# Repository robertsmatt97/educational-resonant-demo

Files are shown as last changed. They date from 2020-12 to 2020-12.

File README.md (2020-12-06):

# Educational Demos for Resonant Converter Phenomena

This repository stores all of the project files corresponding to the paper published under the same name. The files are necessary for building, simulating, and operating the converter described in the paper.

## Navigating the Project Files

1. User Manual
    - A detailed guide for setting up and operating the educational board.
    - The User Manual is listed already in the published paper but will be regularly updated here.
    
2. Bill of Materials
    - An Excel spreadsheet that contains every component used for the educational converter.
    - URLs, part numbers, and prices are listed.
    - Mouser cart link attached (To be added) is at the bottom of the spreadsheet for easy purchasing.
    - It is recommended to buy extra parts.
    
3. GERBER Files Zip File
    - A zip file for PCB manufacturers for convenient PCB purchasing.
    - The zip file is suitable for Smart Prototyping, which was used to create the prototype.
    - Some PCB manufacturers require different export options. The User Manual describes how to export it correctly.
    
4. "Videos" Folder
    - Videos demonstrating the capabilities of the converter. 
    - YouTube links are listed below as well. (To be added)
    - Demonstration 1: (To be added)
    - Demonstration 2: (To be added)
    
5. "KiCAD" Folder
    - KiCAD project files containing the schematic and PCB of the converter.
    - Library paths may need to be configured to see symbols and footprints correctly.
    
6. "MATLAB" Folder
    - MATLAB scripts to show hypothetical, simulation, and converter data over different combinations of resonant converter design parameters.
    - 'Resonant_Design.m' shows hypothetical and simulation data only. The board does not need to be connected.
    - 'Resonant_Design_Serial.m' shows hypothetical, simulation, and converter data. The board needs to be connected, and the CCS script needs to be running.
    - MATLAB 2019b or higher is required to run the 'Resonant_Design_Serial.m' script. 
    
7. "LTSpice" Folder
    - Simulation files for the resonant converter. 
    - Configure the parameters where it is listed.
    - Follow the User Manual for instructions on additional operation.
    
8. "CCS" Folder
    - Code Composer Studio (CCS) project files containing the code needed for operation. 
    - The latest version of CCS is recommended for the converter to work.

## To-Do List

1. Add Mouser Cart link of all the components. 
2. Add YouTube links of video demonstrations.
3. Add more visuals to User Manual.
3. Add additional microcontroller features to shorten downtime for demonstrations.

## Contact Information for Help

You can contact me at my email below for assistance in getting the board to work. Please be detailed in your issues.
Email: robertsmatt97@gmail.com

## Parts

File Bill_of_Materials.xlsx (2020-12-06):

 | Grocery List | Bill of Materials
 |  | Bought | Item Name | Component Label | Part Number | Value | QTY | Price | Total | Datasheet URL | Column1 | Column2
 |  |  | Microcontroller | NA | LAUNCHXL-F280049C | NA | 1 | $36.00 | $36.00 | https://www.ti.com/tool/LAUNCHXL-F280049C#1
 |  |  | 2x10 Socket | J1...J4 | 90151-2320 | NA | 4 | $5.13 | $20.52 | https://www.mouser.com/ProductDetail/Molex/90151-2320?qs=WjPO6T6WDws63RVDMfLJfw%3D%3D
 |  |  | Single Headers | J5+ | 87891-0106 | NA | 14 | $0.21 | $2.94 | https://www.mouser.com/ProductDetail/Molex/87891-0106?qs=kNSQ05%252BLZoC2%252Bs81B6ycXA%3D%3D
 |  |  | MOSFET | Q | CSD18513Q5A | NA | 2 | $1.11 | $2.22 | https://www.mouser.com/ProductDetail/Texas-Instruments/CSD18513Q5A?qs=34RfhUjJmKfal%252BAkBmQt6Q%3D%3D
 |  |  | SPST Rocker Switches | SW | H8800VAAAB | NA | 4 | $1.06 | $4.24 | https://www.digikey.com/en/products/detail/bulgin/H8800VAAAB/9598452?s=N4IgTCBcDaIBIA4EAZkDUCCWBCIC6AvkA
 |  |  | Half Bridge Diodes | D | SL43-M3/57T | NA | 4 | $0.80 | $3.20 | https://www.mouser.com/ProductDetail/Vishay-General-Semiconductor/SL43-M3-57T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
 |  |  | Transformer | T | 750342864 | 50 uH | 1 | $5.76 | $5.76 | https://www.mouser.com/ProductDetail/Wurth-Elektronik/750342864
 |  |  | Resonant Inductor | Lr | 744373965120 | 12 uH | 1 | $2.81 | $2.81 | https://www.mouser.com/ProductDetail/Wurth-Elektronik/744373965120?qs=BZBei1rCqCCwoGZYfs3IVg%3D%3D
 |  |  | Resonant Capacitor 1 | Cr1 | C0805C473F3GECAUTO | 47 nF | 1 | $1.71 | $1.71 | https://www.mouser.com/ProductDetail/KEMET/C0805C473F3GECAUTO?qs=MLItCLRbWsw%2FcVYxjlXEdg%3D%3D
 |  |  | Resonant Capacitor 2 | Cr2 | GRM31C5C2A823JA01L | 82 nF | 2 | $0.71 | $1.42 | https://www.mouser.com/ProductDetail/Murata-Electronics/GRM31C5C2A823JA01L
 |  |  | Magnetizing Inductor | Lmag | 744373965120 | 12 uH | 3 | $2.81 | $8.43 | https://www.mouser.com/ProductDetail/Wurth-Elektronik/744373965120?qs=BZBei1rCqCCwoGZYfs3IVg%3D%3D
 |  |  | Half Bridge Capacitor | Crect | CM105X5R106M25AT | 10 uF | 2 | $0.30 | $0.60 | https://www.mouser.com/ProductDetail/Kyocera-Electronic-Components/CM105X5R106M25AT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
 |  |  | Input Capacitor | Cin | CM105X5R106M25AT | 10 uF | 2 | $0.30 | $0.60 | https://www.mouser.com/ProductDetail/Kyocera-Electronic-Components/CM105X5R106M25AT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
 |  |  | Input Loop Capacitor | Cinx | LLL31MR71C105MA01L | 1 uF | 1 | $0.48 | $0.48 | https://www.mouser.com/ProductDetail/Murata-Electronics/LLL31MR71C105MA01L
 |  |  | Output Capacitor | Cout | CM105X5R106M25AT | 10 uF | 2 | $0.30 | $0.60 | https://www.mouser.com/ProductDetail/Kyocera-Electronic-Components/CM105X5R106M25AT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
 |  |  | Divider Resistor 1 | Rdiv1 | AC0603FR-07100KL | 100 k | 1 | $0.10 | $0.10 | https://www.mouser.com/ProductDetail/Yageo/AC0603FR-07100KL?qs=UoPT7wUmgYKBKZ83mTH%252BSA%3D%3D
 |  |  | Divider Resistor 2 | Rdiv2 | AC0603FR-0720KL | 20 k | 1 | $0.10 | $0.10 | https://www.mouser.com/ProductDetail/Yageo/AC0603FR-0720KL?qs=UoPT7wUmgYLT1v%252BfpbzmVQ%3D%3D
 |  |  | Divider Resistor 3 | Rdiv3 | AC0603FR-07150KL | 150 k | 2 | $0.10 | $0.20 | https://www.mouser.com/ProductDetail/Yageo/AC0603FR-07150KL?qs=yhV1fb9g%2FKbGHv1fnPiGNw%3D%3D
 |  |  | Sensing Resistors | Rsns | WU732B15TTD25L0F | 25 m | 1 | $0.38 | $0.38 | https://www.mouser.com/ProductDetail/KOA-Speer/WU732B15TTD25L0F?qs=wUXugUrL1qyp9SvPCjqdBg%3D%3D
 |  |  | Boost IC | IC | TPS61085TDGKR | NA | 1 | $2.03 | $2.03 | https://www.mouser.com/ProductDetail/Texas-Instruments/TPS61085TDGKR
 |  |  | BB Diode | Dbb | PMEG2010AEH,115 | NA | 1 | $0.32 | $0.32 | https://www.mouser.com/ProductDetail/Nexperia/PMEG2010AEH115?qs=LOCUfHb8d9u7lcjEnyhX1g%3D%3D
 |  |  | BB Cap input | Cbb1 | CM105X5R106M25AT | 10 uF | 1 | $0.30 | $0.30 | https://www.mouser.com/ProductDetail/Kyocera-Electronic-Components/CM105X5R106M25AT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
 |  |  | BB Cap output | Cbb2 | CM105X5R106M25AT | 10 uF | 1 | $0.30 | $0.30 | https://www.mouser.com/ProductDetail/Kyocera-Electronic-Components/CM105X5R106M25AT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
 |  |  | BB Inductor | Lbb | CB2016T6R8M | 6.8 uH | 1 | $0.23 | $0.23 | https://www.mouser.com/ProductDetail/Taiyo-Yuden/CB2016T6R8M?qs=I6KAKw0tg2zlZTrvjf8dKA%3D%3D
 |  |  | BB FB Resistor 1 | Rfb1 | CR0805-FX-1133ELF | 113 k | 1 | $0.10 | $0.10 | https://www.mouser.com/ProductDetail/Bourns/CR0805-FX-1133ELF
 |  |  | BB FB Resistor 2 | Rfb2 | CRCW080518K0FKEA | 18 k | 1 | $0.10 | $0.10 | https://www.mouser.com/ProductDetail/Vishay-Dale/CRCW080518K0FKEA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
 |  |  | BB Comp R | Rcomp | ERA-3AED243V | 24 k | 1 | $0.25 | $0.25 | https://www.mouser.com/ProductDetail/Panasonic/ERA-3AED243V?qs=SWVmE3OSrOmwxrbbukvP0g%3D%3D
 |  |  | BB Comp C | Ccomp | ECH-U1C332GX5 | 3.3 nF | 1 | $0.37 | $0.37 | https://www.mouser.com/ProductDetail/Panasonic/ECH-U1C332GX5?qs=O9nxk9bDVAjmIw2e8gOaeQ%3D%3D
 |  |  | BB SS Cap | Cbb4 | CC0603KRX7R9BB104 | 100 nF | 1 | $0.10 | $0.10 | https://www.mouser.com/ProductDetail/Yageo/CC0603KRX7R9BB104?qs=sGAEpiMZZMvsSlwiRhF8qgFnKIgZe697WZ9nrpNTeGg%3D
 |  |  | BB IN Cap | Cbb3 | TMK107B7105KA-T | 1 uF | 1 | $0.11 | $0.11 | https://www.mouser.com/ProductDetail/Taiyo-Yuden/TMK107B7105KA-T
 |  |  | Gate Driver | G | LM5109BSD/NOPB | NA | 1 | $1.31 | $1.31 | https://www.mouser.com/ProductDetail/Texas-Instruments/LM5109BSD-NOPB?qs=QbsRYf82W3Gksst44udN8Q%3D%3D
 |  |  | GD Diode | Dboot | MBR1H100SFT3G | NA | 1 | $0.44 | $0.44 | https://www.mouser.com/ProductDetail/ON-Semiconductor/MBR1H100SFT3G
 |  |  | GD Bootstrap Resistor | Rboot | ESR03EZPF3R00 | 3 | 1 | $0.13 | $0.13 | https://www.mouser.com/ProductDetail/ROHM-Semiconductor/ESR03EZPF3R00
 |  |  | GD HS Cap | Cboot | CC0603KRX7R9BB104 | 100 nF | 1 | $0.10 | $0.10 | https://www.mouser.com/ProductDetail/Yageo/CC0603KRX7R9BB104?qs=sGAEpiMZZMvsSlwiRhF8qgFnKIgZe697WZ9nrpNTeGg%3D
 |  |  | GD Input Cap | Cgd | TMK107B7105KA-T | 1 uF | 1 | $0.11 | $0.11 | https://www.mouser.com/ProductDetail/Taiyo-Yuden/TMK107B7105KA-T
 |  |  | Signal Op Amp (2 in 1) | U1A…U1C | TLV2314IDR | NA | 1 | $0.94 | $0.94 | https://www.mouser.com/ProductDetail/Texas-Instruments/TLV2314IDR?qs=f4l5qYp%2Fy%252B7ipEpw1sGVYg%3D%3D
 |  |  | Filter Resistor 1 | Rfilt1 | AC0603FR-076K65L | 6.65 k | 2 | $0.10 | $0.20 | https://www.mouser.com/ProductDetail/Yageo/AC0603FR-076K65L?qs=ygRr%2FtkhtevehdG909PYfg%3D%3D
 |  |  | Filter Resistor 1 | Rfilt2 | AC0603FR-07665RL | 665 | 2 | $0.10 | $0.20 | https://www.mouser.com/ProductDetail/Yageo/AC0603FR-07665RL
`` |  |  | Filter Capacitor 1 | Cfilt2 | TMK107B7105KA-T | 1 uF | 2 | $0.11 | $0.22 | https://www.mouser.com/ProductDetail/Taiyo-Yuden/TMK107B7105KA-T
 |  |  | Filter Capacitor 2 | Cfilt1 | CC0603KRX7R9BB104 | 100 nF | 3 | $0.10 | $0.30 | https://www.mouser.com/ProductDetail/Yageo/CC0603KRX7R9BB104?qs=sGAEpiMZZMvsSlwiRhF8qgFnKIgZe697WZ9nrpNTeGg%3D
 |  |  | Frequency Resistors | Rfs | RC0603FR-0747KL | 47 k | 2 | $0.10 | $0.20 | https://www.mouser.com/ProductDetail/Yageo/RC0603FR-0747KL
 |  |  | Frequency Capacitor | Cfs | C0603C103J5RACTU | 10 n | 1 | $0.10 | $0.10 | https://www.mouser.com/ProductDetail/KEMET/C0603C103J5RACTU?qs=sGAEpiMZZMvsSlwiRhF8quIsB1QHp5lf6wge94WzHBg%3D
 |  |  | Potentiometer | RV | PTV09A-4020U-B103 | 1 k (min) | 1 | $0.80 | $0.80 | https://www.mouser.com/ProductDetail/Bourns/PTV09A-4020U-B102
 |  |  |  |  |  |  |  | Total Budget | $101.57

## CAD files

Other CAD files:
CCS/Resonant_Demo/Debug/optimizerAssistant/opt_for_speed__1/Main_Resonant.obj
CCS/Resonant_Demo/Debug/optimizerAssistant/opt_for_speed__2/Main_Resonant.obj
CCS/Resonant_Demo/Debug/optimizerAssistant/opt_for_speed__4/Main_Resonant.obj
CCS/Resonant_Demo/Debug/optimizerAssistant/opt_for_speed__0/Main_Resonant.obj
CCS/Resonant_Demo/Debug/optimizerAssistant/opt_for_speed__5/Main_Resonant.obj
CCS/Resonant_Demo/Debug/optimizerAssistant/opt_for_speed__3/Main_Resonant.obj
CCS/Resonant_Demo/Debug/device/device.obj
CCS/Resonant_Demo/Debug/driverlib/lin.obj
CCS/Resonant_Demo/Debug/optimizerAssistant/opt_for_speed__0/device/device.obj
CCS/Resonant_Demo/Debug/optimizerAssistant/opt_for_speed__0/PWM_Operation.obj
CCS/Resonant_Demo/Debug/optimizerAssistant/opt_for_speed__1/device/device.obj
CCS/Resonant_Demo/Debug/optimizerAssistant/opt_for_speed__2/device/device.obj
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

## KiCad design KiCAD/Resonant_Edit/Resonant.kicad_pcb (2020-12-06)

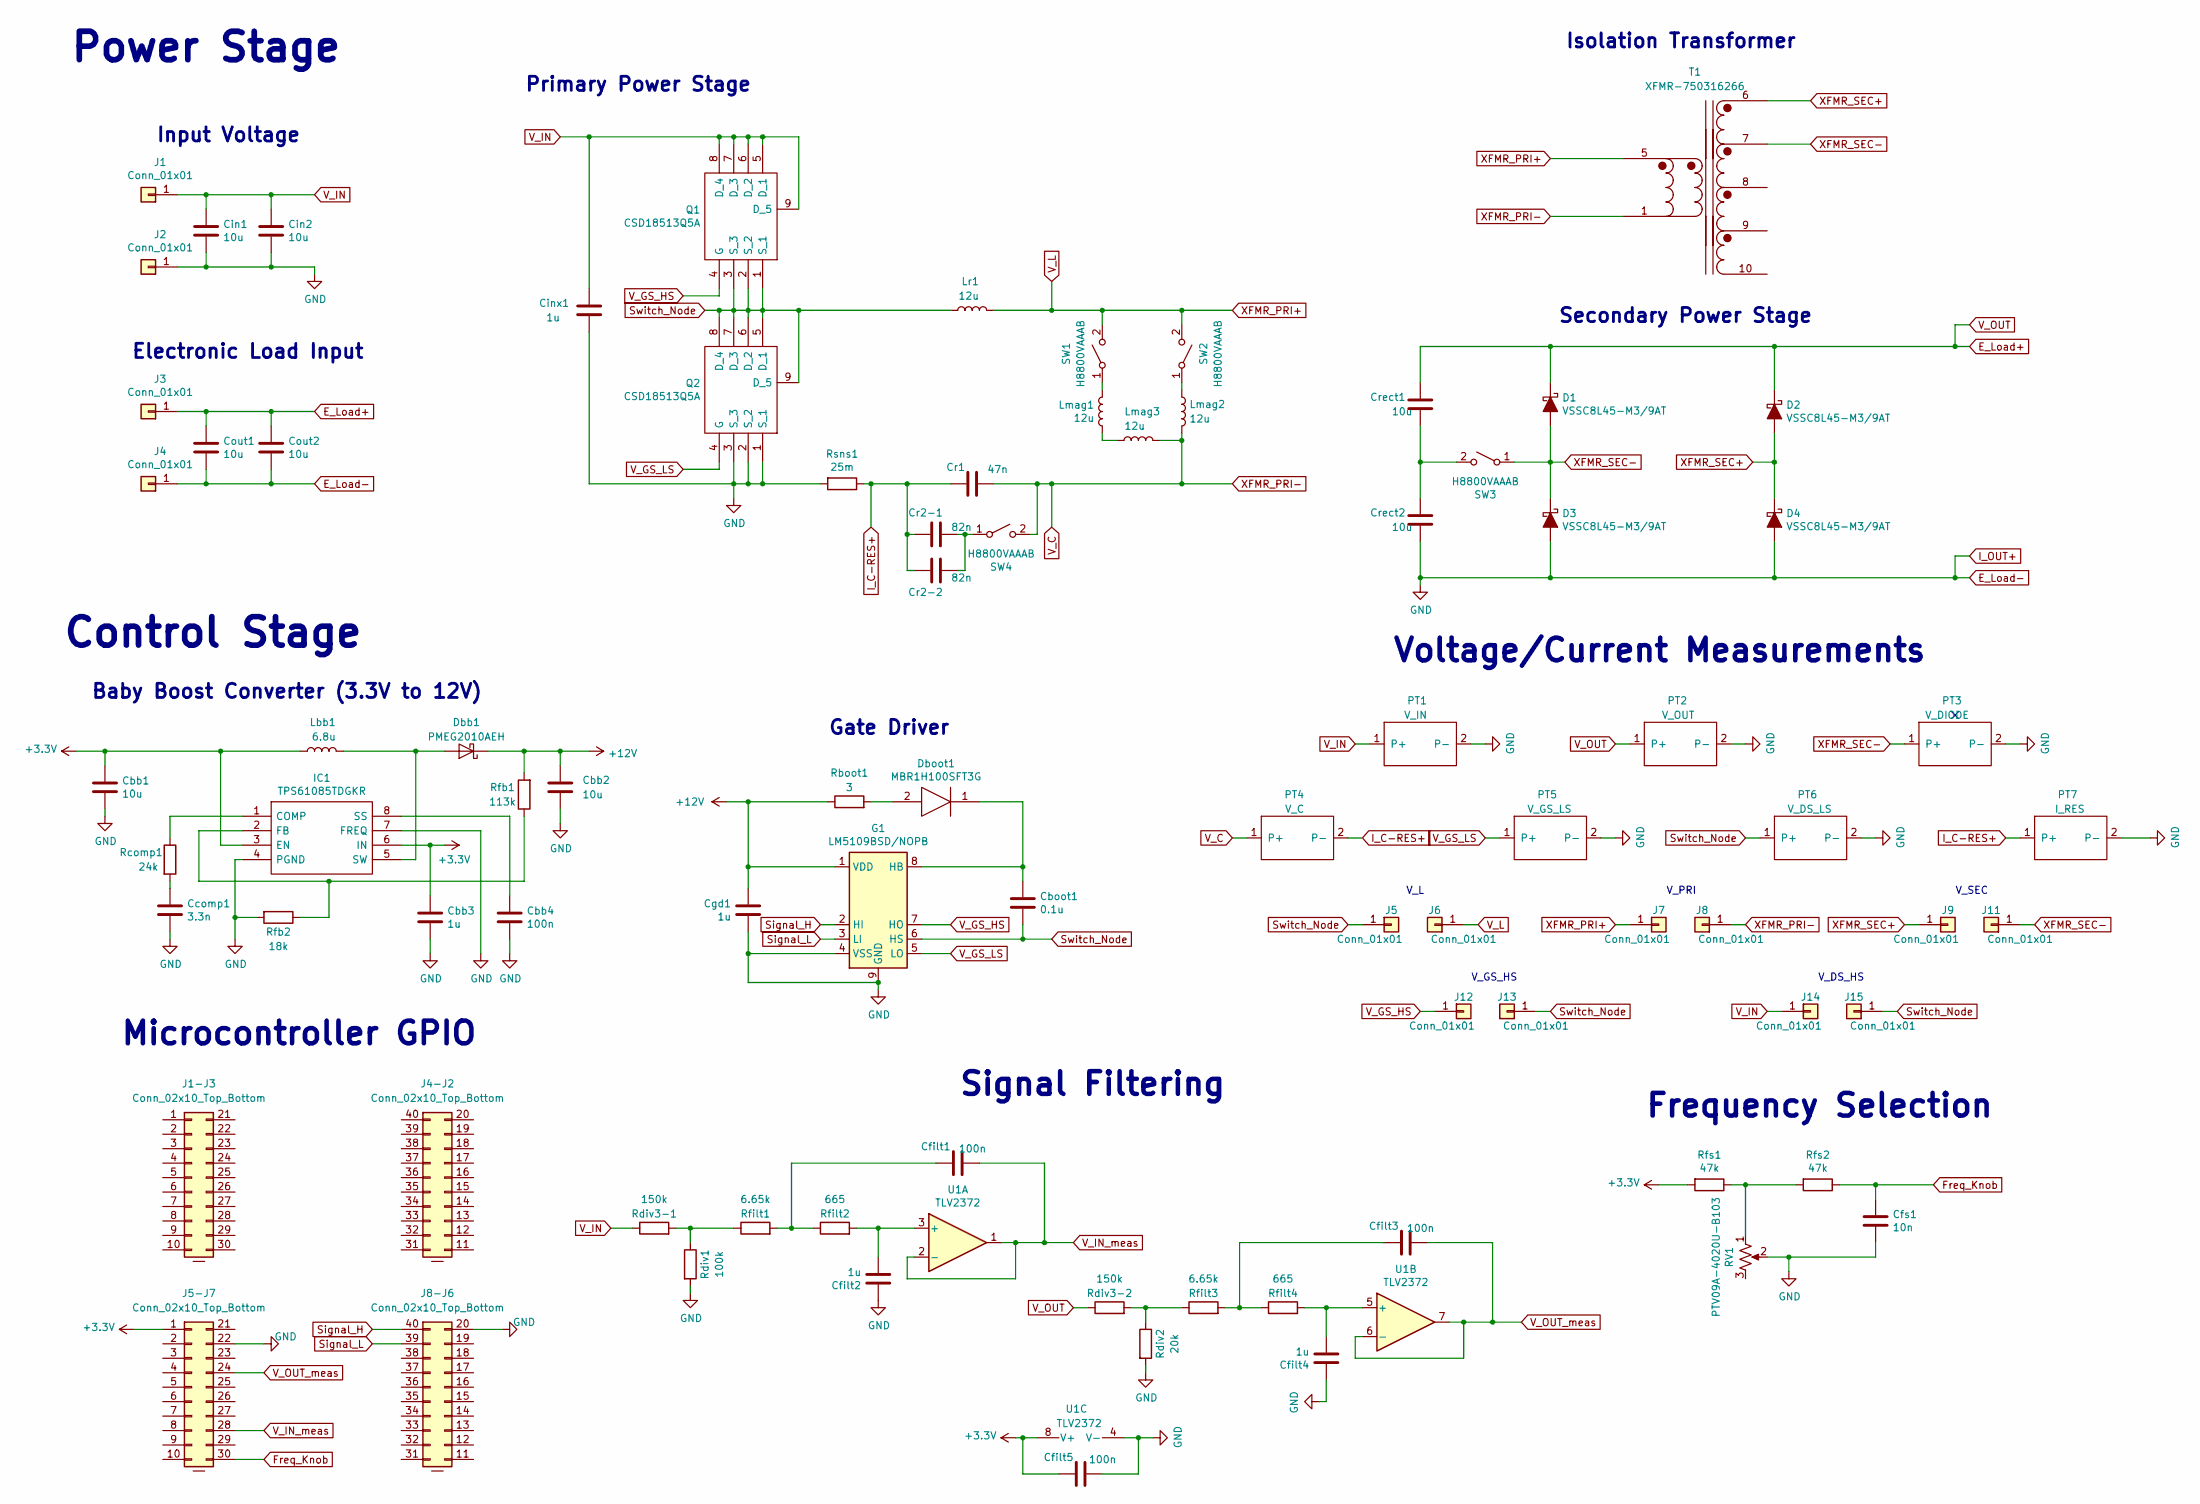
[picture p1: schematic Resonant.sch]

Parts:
Cbb1, Cbb2: 10u; C_0603_1608Metric
Cbb3: 1u; C_0603_1608Metric
Cbb4: 100n; C_0603_1608Metric
Cboot1: 0.1u; C_0603_1608Metric
Ccomp1: 3.3n; C_0805_2012Metric
Cfilt1, Cfilt3, Cfilt5: 100n; C_0603_1608Metric
Cfilt2, Cfilt4: 1u; C_0603_1608Metric
Cfs1: 10n; C_0603_1608Metric
Cgd1: 1u; C_0603_1608Metric
Cin1, Cin2: 10u; C_0603_1608Metric
Cinx1: 1u; LLL31MR71C105MA01L
Cout1, Cout2: 10u; C_0603_1608Metric
Cr1: 47n; C_0805_2012Metric
Cr2-1, Cr2-2: 82n; C_1206_3216Metric
Crect1, Crect2: 10u; C_0603_1608Metric
D1, D2, D3, D4: VSSC8L45-M3/9AT; VSSC8L45-M3_9AT
Dbb1: PMEG2010AEH; D_SOD-123
Dboot1: MBR1H100SFT3G; Mouser Part Number 863-MBR1H100SFT3G
G1: LM5109BSD/NOPB; LM5109BSD_NOPB
IC1: TPS61085TDGKR; Mouser Part Number 595-TPS61085TDGKR
J1, J2, J3, J4, J5, J6, J7, J8, J9, J11, J12, J13, J14, J15: Conn_01x01; PinHeader_1x01_P2.54mm_Vertical
J1-J3, J5-J7: Conn_02x10_Top_Bottom; 90151-2320_J1
J4-J2, J8-J6: Conn_02x10_Top_Bottom; 90151-2320_J2
Lbb1: 6.8u; L_0805_2012Metric
Lmag1, Lmag2, Lmag3: 12u; 744373965120
Lr1: 12u; 744373965120
PT1: V_IN; Probe_Test
PT2: V_OUT; Probe_Test
PT3: V_DIODE; Probe_Test
PT4: V_C; Probe_Test
PT5: V_GS_LS; Probe_Test
PT6: V_DS_LS; Probe_Test
PT7: I_RES; Probe_Test
Q1, Q2: CSD18513Q5A; Mouser Part Number 595-CSD18513Q5A
RV1: PTV09A-4020U-B103
Rboot1: 3; R_0603_1608Metric
Rcomp1: 24k; R_0603_1608Metric
Rdiv1: 100k; R_0603_1608Metric
Rdiv2: 20k; R_0603_1608Metric
Rdiv3-1, Rdiv3-2: 150k; R_0603_1608Metric
Rfb1: 113k; R_0805_2012Metric
Rfb2: 18k; R_0805_2012Metric
Rfilt1, Rfilt3: 6.65k; R_0603_1608Metric
Rfilt2, Rfilt4: 665; R_0603_1608Metric
Rfs1, Rfs2: 47k; R_0603_1608Metric
Rsns1: 25m; R_0612_1632Metric
SW1, SW2, SW3, SW4: H8800VAAAB
T1: XFMR-750316266; 750342864
U1: TLV2372; TLV2632

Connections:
+3V3: Cbb1.1, Cbb3.1, Cfilt5.1, IC1.3 (EN), IC1.6 (IN), J5-J7.1, Lbb1.1, Rfs1.2, U1.8 (V+)
+12V: Cbb2.2, Cgd1.1, Dbb1.1 (K), G1.1 (VDD), Rboot1.1, Rfb1.2
E_Load+: Cout1.1, Cout2.1, Crect1.1, D1.1 (K), D2.1 (K), J3.1, PT2.1 (P+), Rdiv3-2.1
E_Load-: Cbb1.2, Cbb2.1, Cbb3.2, Cbb4.2, Ccomp1.2, Cfilt2.1, Cfilt4.1, Cfilt5.2, Cfs1.2, Cgd1.2, Cin1.2, Cin2.2, Cinx1.2, Cout1.2, Cout2.2, Crect2.2, D3.2 (A), D4.2 (A), G1.4 (VSS), G1.9 (GND), IC1.4 (PGND), IC1.7 (FREQ), J2.1, J4.1, J5-J7.22 (Pin_12), J8-J6.20 (Pin_11), PT1.2 (P-), PT2.2 (P-), PT3.2 (P-), PT5.2 (P-), PT6.2 (P-), PT7.2 (P-), Q2.1 (S_1), Q2.2 (S_2), Q2.3 (S_3), RV1.2, Rdiv1.2, Rdiv2.2, Rfb2.2, Rsns1.2, U1.4 (V-)
Freq_Knob: Cfs1.1, J5-J7.30 (Pin_20), Rfs2.1
I_C-RES+: Cr1.1, Cr2-1.1, Cr2-2.1, PT4.2 (P-), PT7.1 (P+), Rsns1.1
unnamed: Cbb4.1, IC1.8 (SS)
unnamed: Cboot1.1, Dboot1.1, G1.8 (HB)
unnamed: Ccomp1.1, Rcomp1.2
unnamed: Cfilt1.1, Rfilt1.2, Rfilt2.1
unnamed: Cfilt2.2, Rfilt2.2, U1.3 (+)
unnamed: Cfilt3.1, Rfilt3.2, Rfilt4.1
unnamed: Cfilt4.2, Rfilt4.2, U1.5 (+)
unnamed: Cr2-1.2, Cr2-2.2, SW4.1 (A)
unnamed: Crect1.2, Crect2.1, SW3.2 (B)
unnamed: Dbb1.2 (A), IC1.5 (SW), Lbb1.2
unnamed: Dboot1.2, Rboot1.2
unnamed: IC1.1 (COMP), Rcomp1.1
unnamed: IC1.2 (FB), Rfb1.1, Rfb2.1
unnamed: Lmag1.1, SW1.1 (A)
unnamed: Lmag1.2, Lmag3.2
unnamed: Lmag2.2, SW2.1 (A)
unnamed: RV1.1, Rfs1.1, Rfs2.2
unnamed: Rdiv1.1, Rdiv3-1.2, Rfilt1.1
unnamed: Rdiv2.1, Rdiv3-2.2, Rfilt3.1
Signal_H: G1.2 (HI), J8-J6.40 (Pin_1)
Signal_L: G1.3 (LI), J8-J6.39 (Pin_2)
Switch_Node: Cboot1.2, G1.6 (HS), J5.1, J13.1, J15.1, Lr1.1, PT6.1 (P+), Q1.1 (S_1), Q1.2 (S_2), Q1.3 (S_3), Q2.5 (D_1), Q2.6 (D_2), Q2.7 (D_3), Q2.8 (D_4), Q2.9 (D_5)
V_C: Cr1.2, J8.1, Lmag2.1, Lmag3.1, PT4.1 (P+), SW4.2 (B), T1.1 (AB)
V_GS_HS: G1.7 (HO), J12.1, Q1.4 (G)
V_GS_LS: G1.5 (LO), PT5.1 (P+), Q2.4 (G)
V_IN: Cin1.1, Cin2.1, Cinx1.1, J1.1, J14.1, PT1.1 (P+), Q1.5 (D_1), Q1.6 (D_2), Q1.7 (D_3), Q1.8 (D_4), Q1.9 (D_5), Rdiv3-1.1
V_IN_meas: Cfilt1.2, J5-J7.28 (Pin_18), U1.1, U1.2 (-)
V_L: J6.1, J7.1, Lr1.2, SW1.2 (B), SW2.2 (B), T1.5 (AA)
V_OUT_meas: Cfilt3.2, J5-J7.24 (Pin_14), U1.6 (-), U1.7
XFMR_SEC+: D2.2 (A), D4.1 (K), J9.1, T1.6 (SB)
XFMR_SEC-: D1.2 (A), D3.1 (K), J11.1, PT3.1 (P+), SW3.1 (A), T1.7 (SC)

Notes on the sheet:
Primary Power Stage
Secondary Power Stage
Gate Driver
Input Voltage
Baby Boost Converter (3.3V to 12V)
Control Stage
Microcontroller GPIO
Power Stage
Electronic Load Input
Isolation Transformer
Frequency Selection
Signal Filtering
Voltage/Current Measurements
V_L
V_SEC
V_PRI
V_DS_HS
V_GS_HS

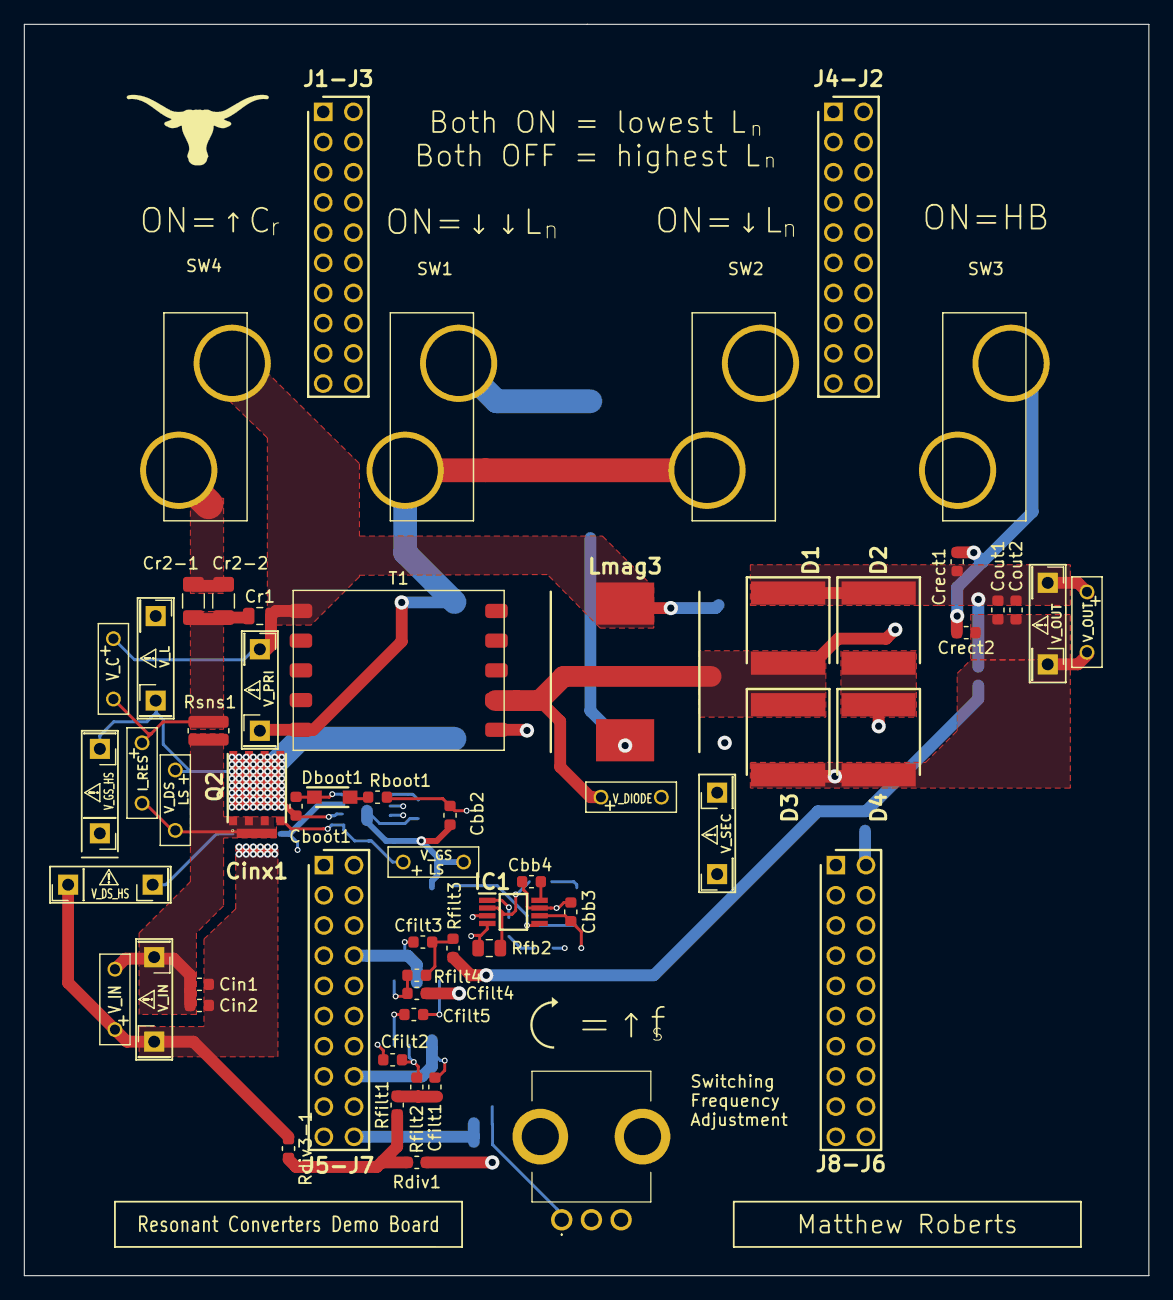
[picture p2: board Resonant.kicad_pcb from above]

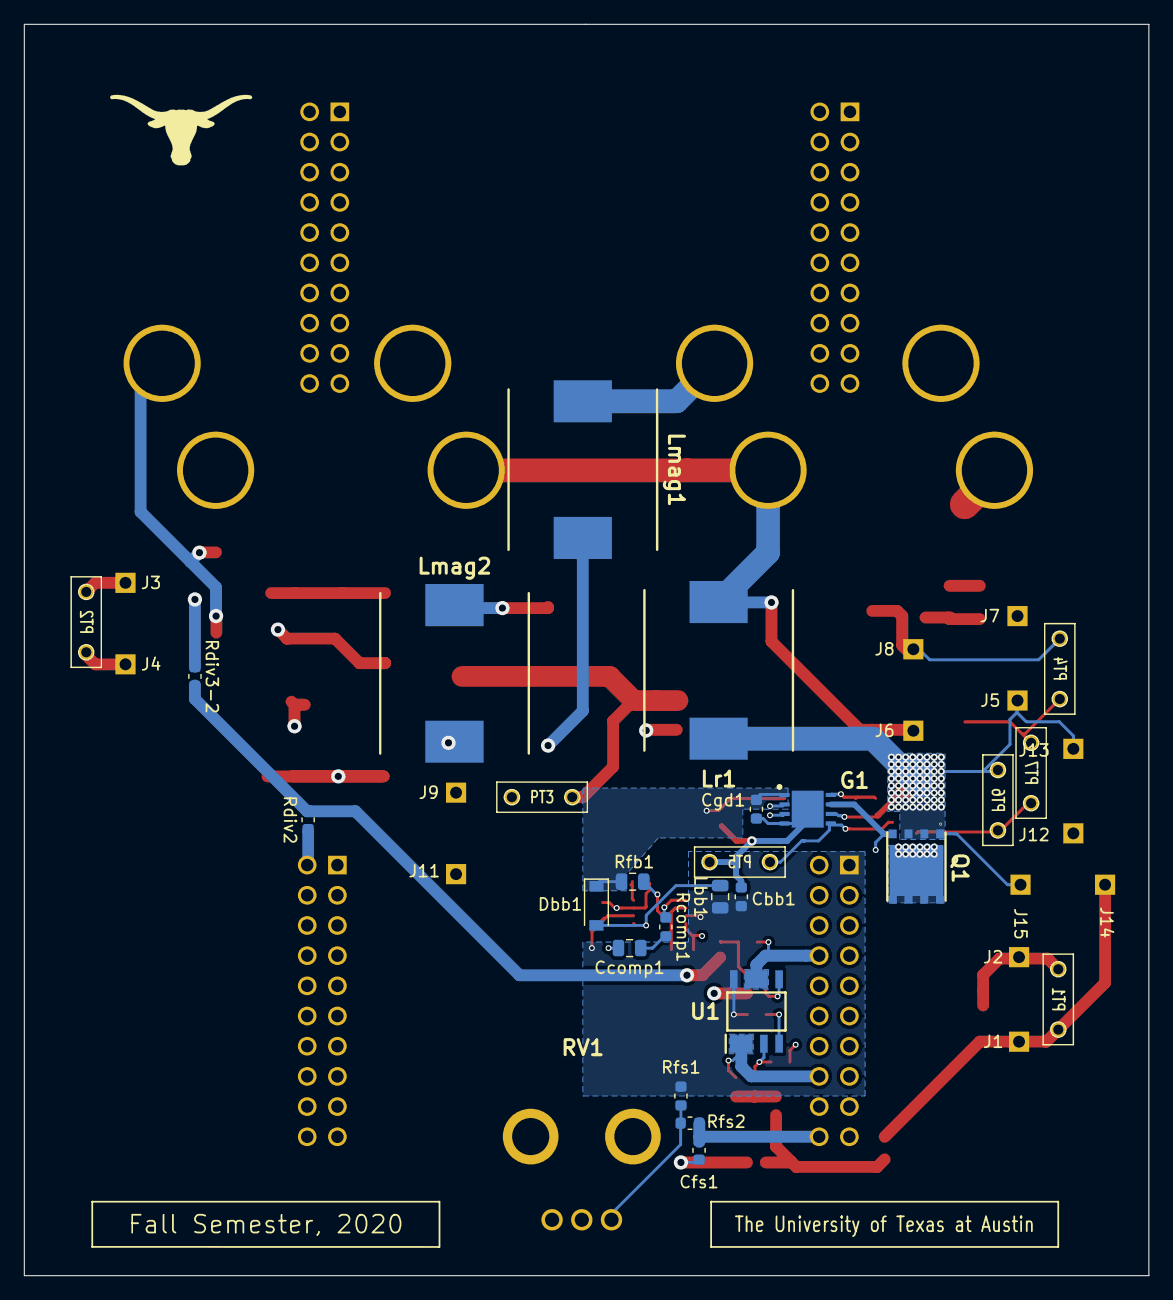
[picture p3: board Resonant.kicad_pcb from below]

Board: 4 copper layers, 94.6 x 105.3 mm, 85 parts (18 on the bottom side), 37 nets.

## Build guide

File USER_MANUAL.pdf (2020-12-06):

# Educational Demos for Resonant Converter Phenomena

# USER MANUAL

## Matthew Roberts

### robertsmatt97@gmail.com https://github.com/robertsmatt97/educational-resonant-demo

1

# Contents

1. User Manual | 4

2

# List of Figures

1.1. Port Settings | 7
1.2. Converter on top of Launchpad to create the Board | 11
1.3. Bench Setup for Demonstration with Input on the Right, Out-
put on the Left | 12
1.4. Expressions for Normal Operation | 13
1.5. Expressions for Calibration | 14

3

# 1 User Manual

This user manual will act as a manual for instructors to set up and operate the board to be used in demonstrations. Before building the converter, one should be aware of the expected hardware needed to use the full extent of the board. Subsection 1 lists the essential hardware used when demonstrating the board:

### The Demonstration requires this set of hardware:

— DC power supply

— 2 Channel Oscilloscope

— Variable or Electronic Load (Rated at 5W minimum)

— At least 1 Passive Voltage Probes

— At least 1 Differential Voltage Probes

— Windows Computer (laptop preferably) with USB-A ports

— MATLAB 2019b or higher

— Latest Version of Code Composer Studio

— Screen to display results on for clear viewing

# 1.1 Demonstration Setup

This section covers every step needed to get the converter in operating conditions. This includes how to set up the GERBER files to order the PCB

4

of the converter, explain the user variables within each script and simulation file, and to get Code Composer Studio to correctly build and debug the submitted CCS Project on your computer.

## 1.1.1 Project Files

The submitted bill of materials (BOM) Excel spreadsheet is to be used when ordering the board’s components. The links to purchase them on Mouser are provided within the spreadsheet under the “URL” column. The submitted zip file named “gerber-files.zip” can be sent directly to most PCB manufacturers as your PCB files. If a manufacturer is not satisfied with the formatting, you can follow the steps shown in Section 1.1.1 to change the export settings through KiCAD. It is unnecessary to follow these steps unless your manufacturer needs a specific export.

### How to export new GERBER files from KiCAD:

1. Install KiCAD 5.0+ onto your computer.

— You can find the download link through KiCAD’s official website, kicad.org.

2. Start KiCAD and open the PCB file, “Resonant.kicad pcb”, by double-clicking the file name.
3. Navigate to File → Plot....
4. Specify the file path of your plot files by pressing the folder icon next to the right of the Output Directory text box.
5. Check or Uncheck options based on what is specified by your PCB manufacturer.

— If your manufacturer has not specified what must be changed, do not continue further. Send the manufacturer the GERBER files already given in the submission files.

— If there are some options you are not seeing that the manufacturer has specified to have, continue onto the next step regardless.

6. Click on Plot, and then click on Generate Drill Files...

5

7. Specify the file path of your drill files by pressing the folder icon next to the right of the Output Folder text box.
8. Check or Uncheck options based on what is specified by your PCB manufacturer.
9. Click on Generate Report File and specify its name.

— Make sure to save it in the same directory as the rest of your exported files.

10. Click on Generate Drill File, then click on Generate Map File.

## 1.1.2 MATLAB and LTSpice

There are two MATLAB scripts submitted: “Resonant Design.m” and “Resonant Design Serial.m”. There are variables seen at the top of the scripts, most of which will be changed during the demonstration. How to properly set these variables will be discussed in Section 1.2.2. However, to set up the MATLAB script “Resonant Design Serial” to receive data from the ADC, the correct serial port should be inserted into the script. Section 1.1.2 provides instructions to find the correct serial port for your computer and put it into the MATLAB script.

### How to configure the MATLAB script to find the right serial port:

1. Plug in the launchpad into your computer with the USB-A cable.

— It is not required to have CCS open, nor the converter attached to the launchpad.

2. Open up the Device Manager on your computer by pressing the Windows Key, typing in “Device Manager”, and pressing Enter.
3. Expand the Ports drop down list, and look for “XDS110 Class Application/User UART”.
4. Note the COM port number.

6

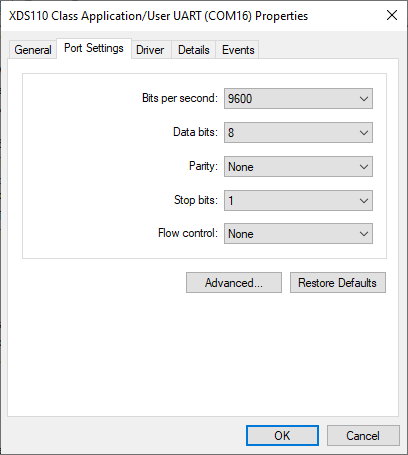
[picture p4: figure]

Figure 1.1: Port Settings

— Example: The COM port number for (COM3) is 3.

— If you do not see the port on the list, verify your launchpad’s connection to the computer or that you have the latest drivers for the launchpad installed.

5. Right-Click the “XDS110 Class Application/User UART” port, and select Properties.
6. Navigate to the Port Settings tab and verify/change the settings to match those in Figure 1.1.
7. Close out of the Properties window.
8. Open up MATLAB and open the MATLAB script, “Resonant Design Serial.m”.
9. Uncomment line 29, %serialportlist, by deleting the “%” from the line.
10. Run the script with the MATLAB console on screen and wait.

— You may encounter an error regarding serial transmission after some time. This is intended.

11. Scroll up on the MATLAB console till you see COM ports. Verify that the COM port number you previously noted is on the list.
12. Edit near the top of the script the variable “port” to match the COM port you noted in the Device Manager and MATLAB console.

7

Unlike the MATLAB scripts, it is recommended to setup LTSpice waveform data before your demonstration. Both MATLAB scripts import LT-Spice data through a text file. Since gathering the data from LTSpice takes at least five minutes, having the text files generated beforehand will minimize downtime during demonstrations. There are three LTSpice files: a full-bridge configuration, a half-bridge configuration, and an FHA simulation. Section 1.1.2 demonstrates how to run the LTSpice simulation and then export its data into a text file.

### How to set up LTSpice simulations for your demonstration:

1. Install LTSpice XVII onto your computer.

— You can find the download link through the Analog Devices website, analog.com, under Design Center.

2. Open LTSpice and open the desired simulation file.
3. Edit the configurable parameters by right-clicking the black “.param” line between the blue “Configure Parameters here:” lines.
4. Click Cancel and type in the desired parameters in the second new window in the format initially present. Click OK when finished.

— You can denote milli, micro, and nano units by adding an “m”, “u”, or “n” at the end of the value.

— Example: “200m” is 200 milli, or 0.2.

5. Run the simulation by clicking on the “running man” icon and patiently wait.

— This process may take a long time depending on your computer’s specs. It may take around 20 minutes on lower-end computers.

— Simulation progress can be tracked on the bottom left corner of the window.

6. After completion, press Ctrl+l to open the Error Log.

8

7. Right-click the open white space in the Error Log and click Plot .step’ed .meas data. A graph of gain versus switching frequency will appear.
8. Right-click the open black space in the Waveform viewer and go to File → Export data as Text.
9. Click on Browse and navigate to the “Sim Text Files” folder under the MATLAB folder from the submitted files.
10. Change the file name, click Save, and then press OK.

## 1.1.3 Code Composer Studio

Code Composer Studio (CCS) requires many steps to build imported projects properly. It is essential to use the latest version of the selected compiler and the software, or else the project may not build. Section 1.1.3 is an extensive set of instructions to set up the CCS project for running the microcontroller script onto the launchpad.

### How to set up Code Composer Studio for demonstration use:

1. Install the latest version of Code Composer Studio, version 3.03.00 of C2000Ware, and version 20.8.0.STS of the C2000 Compiler (version C2000-CGT-21 of C2000 Code Generation Tools).

— All the listed software can be downloaded from Texas Instruments’ website, ti.com.

2. Open CCS and define the workspace in the “CCS” folder of the submitted files.
3. Click the Copy Settings drop-down and check all three boxes. Afterwards, click Launch.
4. Navigate to File → Import... and click on it.
5. Click the Code Composer Studio drop down, click on CCS Projects, and finally click Next.

9

6. Click Browse, and choose the directory of the submitted CCS Project Resonant Demo under “CCS”. Afterwards, click Finish.

— It is best to click the folder “Resonant Demo”, and click “Select Folder”.

7. Right-click the Project “Resonant Demo”, and go to Properties.
8. Verify that you have no warning signs in the CCS General tab. Click Apply and Close.

— If you see errors, you should make sure you have chosen the right compiler version from the drop-down list. If the version does not show up, you do not have the compiler installed properly. Reinstall the compiler and restart your computer.

— If you encounter linker errors, be sure that your workspace directory does not contain spaces or non-ASCII characters.

9. Right-click the project again and click Rebuild Project, and wait.

— Alternatively, you can press the “bug” icon, located towards the top right of the window, to debug the script. Pressing the debug icon will always rebuild the project.

10. If you see “Build Finished” in the console, typically located at the bottom of the window, you have successfully set up your CCS Project.
11. Plug in your launchpad into your computer using the USB-A cable.
12. Click the debug icon and wait until the “play” icon, towards the top of the window, turns from a clear gray to a green and yellow color.
13. You can start the script by clicking the play icon.

## 1.1.4 Assembly

After the converter has had its components soldered onto it, it needs to attach to the launchpad and connect itself to a power supply and load. Section 1.1.4 briefly describes setting up the physical converter to ready for operation.

10

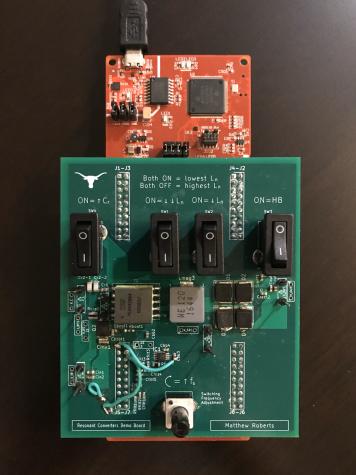
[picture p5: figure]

Figure 1.2: Converter on top of Launchpad to create the Board

### How to set up the converter for operation:

1. Take your completed converter and attach it onto the launchpad from above, matching the orientation seen in Figure 1.2.

— The potentiometer should be on the opposite side of the USB port of the launchpad.

2. Slowly insert the pin sockets of the converter onto the microcontroller’s pin headers, making sure all pins are correctly inserted.
3. Plug in the USB-A cable into the microcontroller, and then into the computer
4. Clip onto the converter’s input and output voltage pins with the DC Power Supply and the Electronic/Variable Load.

— Your bench should look similar to what is seen in Figure 1.3.

11

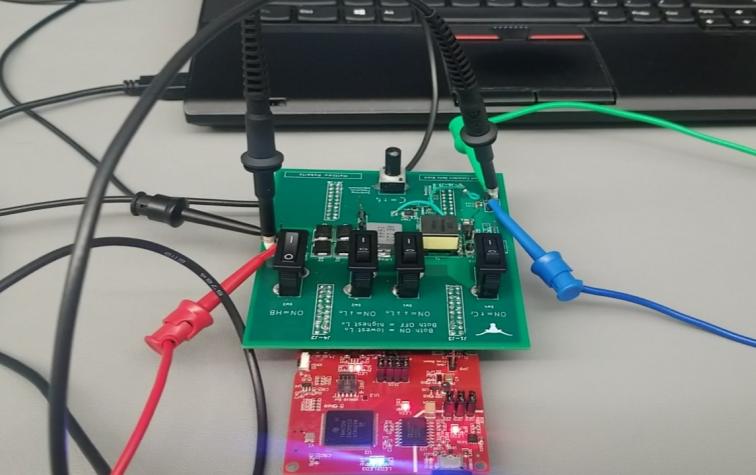
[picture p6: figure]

Figure 1.3: Bench Setup for Demonstration with Input on the Right, Output on the Left

# 1.2 How to use the Board

During the demonstration, the MATLAB and CCS script variables may need to be changed to show different results for different design parameters or configurations. This section will briefly explain how to change these variables based on operation mode and change between the modes.

## 1.2.1 Variable Switching Frequency Operation

This mode allows the user to change the switching frequency in realtime. The switching frequency, input voltage, and output voltage can be seen through CCS’s expression viewer. Section 1.2.1 describes how to set the CCS script to run in this mode and shows how to view ADC inputs.

### How to set up Variable Switching Frequency Mode (No Sweeping):

1. Open Code Composer Studio and open the project up by double-clicking the Project under the “Project Explorer”.

— This should list all the files in the project directory.

12

Figure 1.4: Expressions for Normal Operation

2. Double click the file “Main Resonant.c” to open the file in the “Shared Area”.
3. Under the “Operation Mode” comment section starting on line 20, set both flags to 1.
4. Configure the desired options under the “Normal Operation Parameters” comment section starting on line 30.
5. Save the file and rebuild the project.
6. Plug in the launchpad with the converter attached and debug the project.
7. Open the expressions tab located in the top right corner and insert the expressions in the “Name” column shown in Figure 1.4.

— You may need to open up the expressions window by navigating to View → Expressions.

8. Connect the input and output sides of the converter to the power supply and load if you have not done so already.
9. Turn on the power supply at the desired voltage.
10. Click the green and yellow play button.
11. Turn the potentiometer knob and observe “fs mod”change.

Keep in mind that no voltage gain data will be plotted in this operation, so it is recommended that gain be shown on an oscilloscope over the expression viewer for easier visualization of trends.

13

Figure 1.5: Expressions for Calibration

## 1.2.2 Sweeping across Frequency Operation

This mode enables the converter to sweep over a user-defined frequency range, recording voltage gain for every step. The results will be plotted into MATLAB when both scripts are running in a particular order. Firstly, the ADC must be calibrated to give accurate readings. Section 1.2.2 explains the process of how to calibrate the ADCs.

### How to calibrate the ADCs:

1. Follow the steps in Section 1.2.1, but have the expressions match those in Figure 1.5.
2. Debug the project and start the script.
3. Attach probes onto the input and output voltage test points, either simultaneously or one at a time.
4. Turn the power supply on and observe the readings on the oscilloscope.

— It is recommended to use the DC measurement on your oscilloscope to get a more accurate reading.

— These measurements will be referred to as “Vin measurement” and “Vout measurement”.

5. Following the formulas at lines 26 and 27 of the “Main Resonant.c” code, use the expressions viewer’s values and the readings from the oscilloscope to calculate and insert the voltage calibrations.
6. Turn off the power supply and stop the script.

14

Now the data can be read correctly. It is crucial that both the CCS script and MATLAB script have certain variables changed to match the converter’s configuration. Section 1.2.2 describes how to set the CCS script to run in this mode and achieve juxtaposed results on the MATLAB plots.

### How to set up Sweeping Frequency Mode:

1. Open Code Composer Studio and open the project up by double-clicking the Project under the “Project Explorer”.
2. Double click the file “Main Resonant.c” to open the file in the “Shared Area”.
3. Under the “Operation Mode” comment section starting on line 20, set both flags to 0.
4. Configure the desired sweeping options under the “Sweeping Parameters” comment section starting on line 35.
5. Open the MATLAB script file “Resonant Design Serial.m”
6. Plug in the launchpad with the converter attached and debug the project.
7. Connect the input and output sides of the converter to the power supply and load if you have not done so already.
8. Turn on the power supply at the desired voltage.
9. Click the green and yellow play button.
10. Run the MATLAB script and wait patiently.

— This process may take a minute or two. The “pause” variable in the MATLAB script can be changed to lengthen or shorten the time MATLAB ends its transmission.

— It is suggested not to change this value unless one is getting errors in the MATLAB script.

11. Once the MATLAB plots have popped up, the CCS script can be stopped, and the power supply turned off unless one wants to remain in regular operation.

15

After the sweeping has finished, the board will default back into the variable switching frequency mode. If one plans on showing another plot, both scripts must be rerun by following the steps in Figure 1.2.2.

# 1.3 Demonstration Warnings

## 1.3.1 Warnings

To prevent equipment or board damage, one must follow the warnings covered in this section. It is recommended to reread the warnings section right before a demonstration. If multiple people are demonstrating the device or if there are any assistants in the demonstration, it is highly advised that every person involved reads this section. Figure 1.3.1 details these warnings:

### Every person involved in the demonstration must read the following:

1. Do not put a connected load higher than 50 Ω. Higher, unintended loads will quickly destroy on-board components.
2. Pay attention to the orientation of passive probes for the test points.
3. Open loads are fine and will not break the equipment.

— The positive side of the test point will have a plus sign located close to it.

4. Do not use passive probes on the differential probe test points.

— Differential probe test points will have a caution symbol located in the middle of the label.

5. Do not leave the board and the supply unattended, even when the CCS script is not running.
6. Do not alter the CCS code without complete knowledge of what you are doing.
7. Do not substitute the resonant component values with different ones.

16

8. Be gentle with inserting and removing the converter shield onto the launchpad.

17

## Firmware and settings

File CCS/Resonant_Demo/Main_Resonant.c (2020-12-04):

/*
 *  Main_Resonant.c
 *
 *  Fall 2020
 *  Matthew Roberts
 *  The University of Texas at Austin
 */

#include "PWM_Operation.h"
#include "Init_Resonant.h"
#include "F28x_Project.h"
#include "device.h"
#include "board.h"
#include "driverlib.h"
#include <stdint.h>
#include <stdio.h>
#include <stdlib.h>
#include <math.h>

/*********************OPERATION MODE***************************/
volatile uint32_t ramp_flag = 0;                                // Set to 1 if you don't want to sweep, else set to 0
volatile uint16_t SCI_check = 0;                                // Set to 1 if you don't want to sweep, else set to 0
/**************************************************************/

/***************FREQUENCY CALIBRATION PARAMETERS***************/
#define LOWER_FREQUENCY 45000                                   // The lowest frequency you want the potentiometer to reach
#define UPPER_FREQUENCY 130000                                  // The highest frequency you want the potentiometer to reach
/**************************************************************/

/*******************SWEEPING PARAMETERS************************/
#define SWEEP_LOWER 20000                                       // The first frequency to be swept over
#define SWEEP_UPPER 210000                                      // The last frequency to be swept over

// If you are not sure what the below values should be, do not edit them.
#define TOTAL_TIME 10000                                        // The total amount of time spent sweeping, in milliseconds
#define RAMP_RESOLUTION 100                                     // The time between taking each sample, in milliseconds
/**************************************************************/

/*******************CALIBRATION VALUES*************************/
volatile const double Vin_calibrate = 1.9697;                   // Vin_calibrate = Vin_board / Vin_temp
volatile const double Vout_calibrate = 7.359;                   // Vout_calibrate = Vout_board / Vout_temp
/**************************************************************/

/***********************DO NOT EDIT****************************/
#define UPP_MULTIPLIER 1.15
float Duty = 0.5;
const double sweep_rate = (SWEEP_UPPER - SWEEP_LOWER)/(TOTAL_TIME / RAMP_RESOLUTION); // Hz/Sample
volatile double ramp_value = 0;

volatile double AdcResult[3], Adc_sweep_Result[2];
volatile double Vin, Vin_temp, Vout, Vout_temp, KnobPrd, fs_mod, fs = SWEEP_LOWER;

char data_buff[60];
uint16_t SCI_Status = 0U;
volatile uint16_t buff_length = 0;
uint16_t EndChar = '\n';
uint16_t sendChar = 'P';
uint16_t receivedChar;
uint16_t errorCount = 0;
unsigned char *msg;
/**************************************************************/

void main()
{

    // Initializing functions
    Resonant_Init();
    #ifdef AUTOBAUD
        //
        // Perform an autobaud lock.
        // SCI expects an 'a' or 'A' to lock the baud rate.
        //
        SCI_lockAutobaud(SCIA_BASE);
    #endif

    // Verify connection with MATLAB script
    while(SCI_check == 0)
    {
        // Check received character
        receivedChar = SCI_readCharBlockingFIFO(mySCI0_BASE);

        if((SCI_Status & SCI_RXSTATUS_ERROR) != 0)
        {
            ESTOP0;
        }

        // If the received character is not correct
        if(receivedChar != sendChar)
        {
            errorCount++;
        } else
        {
            SCI_disableModule(mySCI0_BASE);
            SCI_check = 1;
        }
    }

    // Enable Interrupts
    EINT;
    ERTM;

    if(ramp_flag == 0)
        {SCI_enableModule(mySCI0_BASE);}

    // Wait for data to be sent to MATLAB
    while(ramp_flag == 0)
    {
        EPwm1Regs.ETCLR.bit.INT = 1;
        EPwm1Regs.ETCLR.bit.SOCA = 1;
    }

    CpuTimer0Regs.TCR.bit.TSS = 1;                              // Stop timer

    // Send End of Transmission Character to MATLAB
    if(SCI_getRxFIFOStatus(mySCI0_BASE) == SCI_FIFO_RX0)
    {SCI_writeCharNonBlocking(mySCI0_BASE, EndChar);}
    SCI_disableModule(mySCI0_BASE);

    // Normal Operation
    for(;;)
    {
        EPwm1Regs.ETCLR.bit.INT = 1;
        EPwm1Regs.ETCLR.bit.SOCA = 1;
    }
}

__interrupt void Freq_Mod()
{

    // Enable Interrupts
    Interrupt_clearACKGroup(0xFFFFU);
    EINT;
    if(ramp_flag == 0)
    {
        // Continue sweeping
        KnobPrd = (100000000/fs) - 1;
        PWM_SET(Duty, KnobPrd);

    } else
    {
        // Any Result from the ADC will give: ADCRESULT = 4096*(ADCIN / 3.3) where ADCIN is the analog input voltage (0-3.3v)
        AdcResult[0] = AdcaResultRegs.ADCRESULT0;               // knob for switching period
        AdcResult[1] = AdccResultRegs.ADCRESULT0;               // Vin
        AdcResult[2] = AdcbResultRegs.ADCRESULT0;               // Vout

        fs_mod = (((AdcResult[0]/4096.0)*((UPPER_FREQUENCY*UPP_MULTIPLIER)-LOWER_FREQUENCY))) + LOWER_FREQUENCY;
        KnobPrd = (100000000/fs_mod) - 1;                       // / prd is the period counter value, which can be calculated as prd = 100Meg/fs.
        Vin = AdcResult[1]*(3.3/4096) * (Vin_calibrate);
        Vout = AdcResult[2]*(3.3/4096) * (Vout_calibrate);

        // Set switching frequency based on Potentiometer position
        PWM_SET(Duty, KnobPrd);

    }

    PieCtrlRegs.PIEACK.bit.ACK3 = 1;                            // Clears the group 1 PIEACK bit so that another interrupt may be handled now
    DINT;

}

__interrupt void Sweep_Routine()
{

    // Enable Interrupts
    Interrupt_clearACKGroup(0xFFFFU);
    __asm("  NOP");
    EINT;

    if(ramp_flag == 0)
    {
        // Checks for end of sweep
        if (fs >= SWEEP_UPPER)
        {
            ramp_flag = 1;
        }

        if(buff_length > 0)
        {SCI_writeCharArray(SCIA_BASE, (uint16_t*)data_buff, 21);}

        // Any Result from the ADC will give: ADCRESULT = 4096*(ADCIN / 3.3) where ADCIN is the analog input voltage (0-3.3v)
        Adc_sweep_Result[0] = AdccResultRegs.ADCRESULT0;    // Vin
        Adc_sweep_Result[1] = AdcbResultRegs.ADCRESULT0;    // Vout

        // Converting Results
        Vin_temp = Adc_sweep_Result[0]*(3.3/4096);
        Vout_temp = Adc_sweep_Result[1]*(3.3/4096);
        Vin = Adc_sweep_Result[0]*(3.3/4096) * (Vin_calibrate);
        Vout = Adc_sweep_Result[1]*(3.3/4096) * (Vout_calibrate);

        // Write Data into buffer
        buff_length = sprintf(data_buff,"%5d,%2d,%04d,%2d,%04d",(int) round(fs/100),(int) Vin, (int) ((Vin - (int) Vin ) * 10000),(int) Vout, (int) ((Vout - (int) Vout ) * 10000)); // @suppress("Invalid arguments")

        // Update fs
        ramp_value += sweep_rate;
        fs = ramp_value + SWEEP_LOWER;

        PieCtrlRegs.PIEACK.bit.ACK1 = 1;                    // Clears the group 3 PIEACK bit so that another interrupt may be handled

    } else
    {
        ;
    }
    DINT;

}

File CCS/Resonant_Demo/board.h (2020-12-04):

/*
 * Copyright (c) 2020 Texas Instruments Incorporated - http://www.ti.com
 * All rights reserved.
 *
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
 * *  Redistributions of source code must retain the above copyright
 *    notice, this list of conditions and the following disclaimer.
 *
 * *  Redistributions in binary form must reproduce the above copyright
 *    notice, this list of conditions and the following disclaimer in the
 *    documentation and/or other materials provided with the distribution.
 *
 * *  Neither the name of Texas Instruments Incorporated nor the names of
 *    its contributors may be used to endorse or promote products derived
 *    from this software without specific prior written permission.
 *
 * THIS SOFTWARE IS PROVIDED BY THE COPYRIGHT HOLDERS AND CONTRIBUTORS "AS IS"
 * AND ANY EXPRESS OR IMPLIED WARRANTIES, INCLUDING, BUT NOT LIMITED TO,
 * THE IMPLIED WARRANTIES OF MERCHANTABILITY AND FITNESS FOR A PARTICULAR
 * PURPOSE ARE DISCLAIMED. IN NO EVENT SHALL THE COPYRIGHT OWNER OR
 * CONTRIBUTORS BE LIABLE FOR ANY DIRECT, INDIRECT, INCIDENTAL, SPECIAL,
 * EXEMPLARY, OR CONSEQUENTIAL DAMAGES (INCLUDING, BUT NOT LIMITED TO,
 * PROCUREMENT OF SUBSTITUTE GOODS OR SERVICES; LOSS OF USE, DATA, OR PROFITS;
 * OR BUSINESS INTERRUPTION) HOWEVER CAUSED AND ON ANY THEORY OF LIABILITY,
 * WHETHER IN CONTRACT, STRICT LIABILITY, OR TORT (INCLUDING NEGLIGENCE OR
 * OTHERWISE) ARISING IN ANY WAY OUT OF THE USE OF THIS SOFTWARE,
 * EVEN IF ADVISED OF THE POSSIBILITY OF SUCH DAMAGE.
 *
 */

#ifndef BOARD_H
#define BOARD_H

//
// Included Files
//

#include "driverlib.h"
#include "device.h"

#define GPIO_PIN_EPWM1_A 0
#define GPIO_PIN_EPWM1_B 1
#define GPIO_PIN_SCIA_RX 43
#define GPIO_PIN_SCIA_TX 44

#define myEPWM0_BASE EPWM1_BASE

#define mySCI0_BASE SCIA_BASE
#define mySCI0_BAUDRATE 9600

void	EPWM_init();
void	SCI_init();
void	PinMux_init();

#endif  // end of BOARD_H definition

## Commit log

2020-12-04 Added initial documents
    First Commit
    [744373965120.stl, 744373965120.stp, ADC_Operation.obj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]
2020-12-05 Added BOM
    Added the Bill of Materials of the Converter
    [Bill_of_Materials.xlsx]
2020-12-06 Final 2020 changes to files
    [744373965120.stl, 744373965120.stp, Bill_of_Materials.xlsx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]
